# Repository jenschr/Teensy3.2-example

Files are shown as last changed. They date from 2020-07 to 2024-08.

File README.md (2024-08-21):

# Teensy3.2-example
A verified example PCB based on the Teensy 3.2 schematics. This repository holds the Kicad files to create your own Teensy 3.2 PCB. Design notes can be found on [my blog](https://flashgamer.com/blog/comments/teensy-3.2-kicad-example).

I'm a consultant based in Oslo/Norway, so [get in touch](https://maketronics.no/about/) if you need custom hardware based on Teensy 4.x (Since Teensy 3.x is no longer feasible due to parts shortage)

Pictures of the finished board can be [found here](images/).

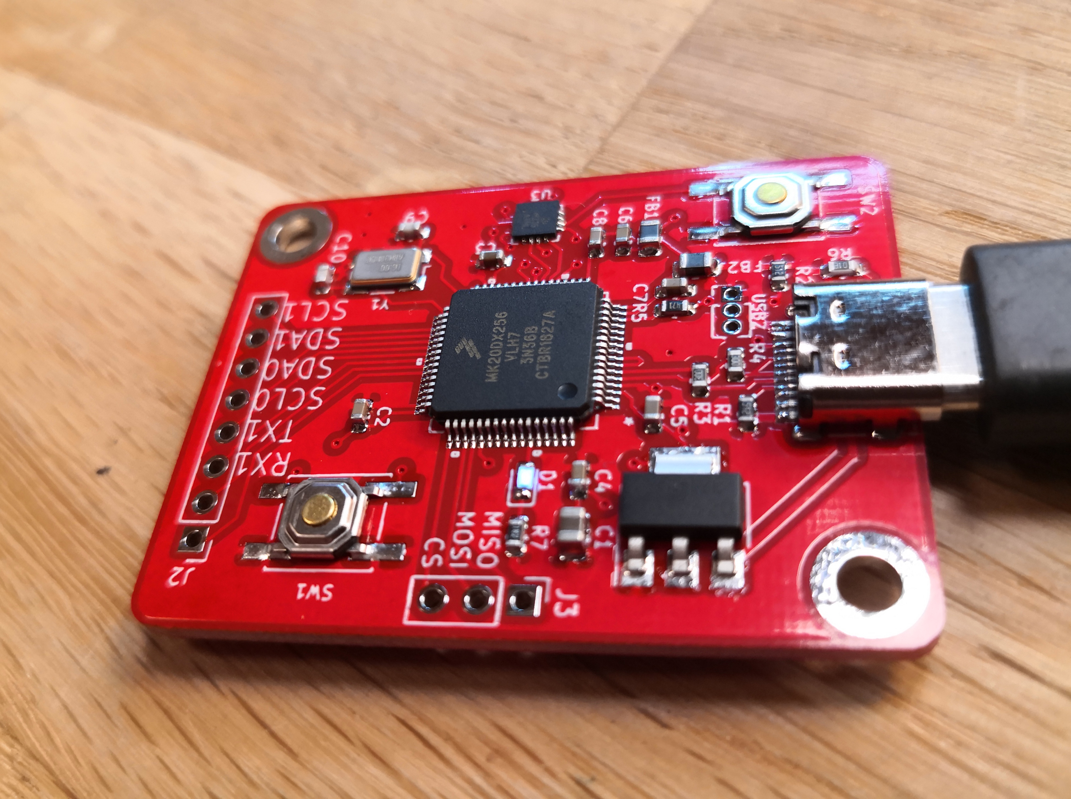
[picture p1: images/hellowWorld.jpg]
Finished PCB


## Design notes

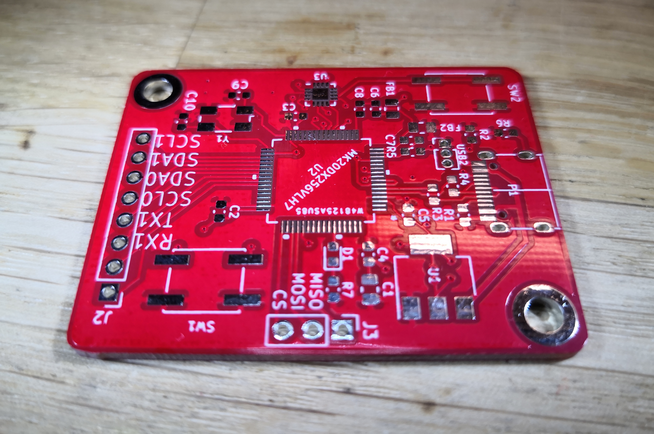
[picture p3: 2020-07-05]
images/unpopulated.jpg

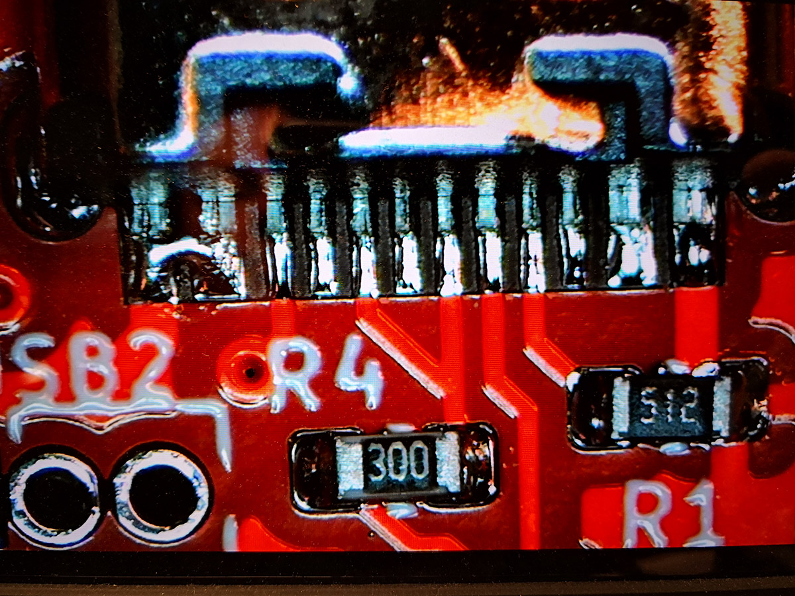
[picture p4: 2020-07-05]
images/short.jpg

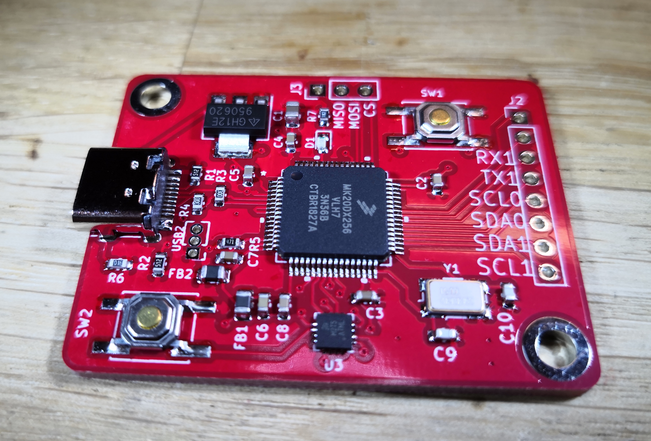
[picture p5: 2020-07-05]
images/populated_w_short_on_usb.jpg

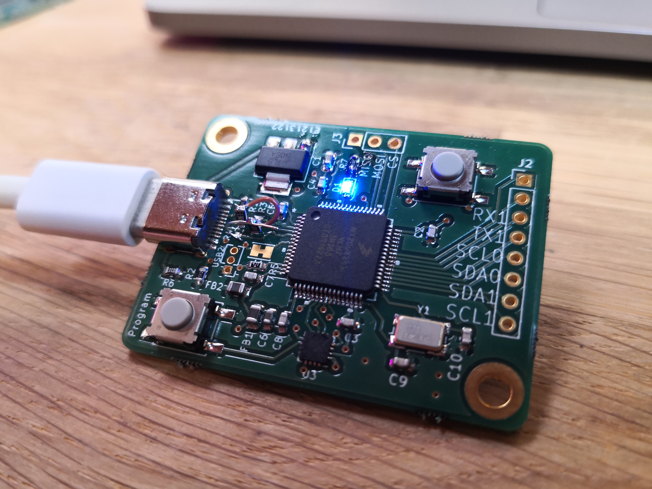
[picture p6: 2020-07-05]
images/version1.0_data_lines_swapped.jpg

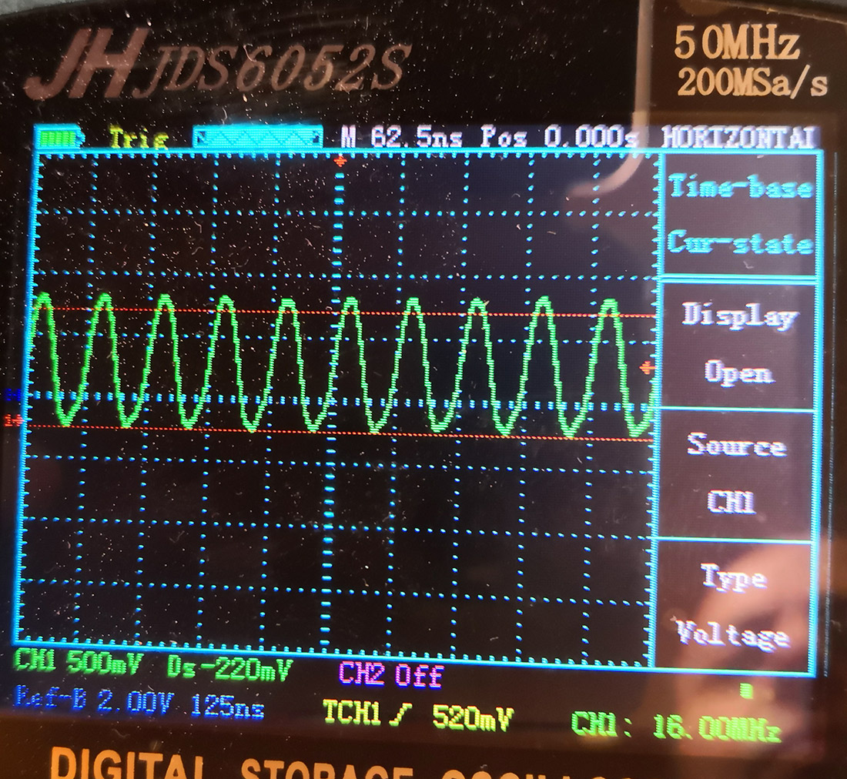
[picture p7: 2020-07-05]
images/oscillating.jpg

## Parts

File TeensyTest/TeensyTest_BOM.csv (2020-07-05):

Ref | Value | Footprint | MPN | MFGR
C1 | 10uF | Capacitor_SMD:C_0805_2012Metric
C2 | 0.1uF | Capacitor_SMD:C_0603_1608Metric
C3 | 0.1uF | Capacitor_SMD:C_0603_1608Metric
C4 | 0.1uF | Capacitor_SMD:C_0603_1608Metric
C5 | 0.1uF | Capacitor_SMD:C_0603_1608Metric
C6 | 2.2uF | Resistor_SMD:R_0603_1608Metric
C7 | 0.1uF | Capacitor_SMD:C_0603_1608Metric
C8 | 0.1uF | Capacitor_SMD:C_0603_1608Metric
C9 | 10pF | Capacitor_SMD:C_0603_1608Metric | 885012006002‎ | Wurth
C10 | 10pF | Capacitor_SMD:C_0603_1608Metric | 885012006002‎ | Wurth
D1 | LED_Small | LED_SMD:LED_0603_1608Metric
FB1 | Ferrite_Bead_Small | Resistor_SMD:R_0805_2012Metric | MZ1608-601Y | Bourns
FB2 | Ferrite_Bead_Small | Resistor_SMD:R_0805_2012Metric | MZ1608-601Y | Bourns
H1 | MountingHole | MountingHole:MountingHole_3.2mm_M3_DIN965_Pad
H2 | MountingHole | MountingHole:MountingHole_3.2mm_M3_DIN965_Pad
J2 | Conn_01x08_Female | Connector_PinHeader_2.54mm:PinHeader_1x08_P2.54mm_Vertical
J3 | Conn_01x03_Female | Connector_PinHeader_2.54mm:PinHeader_1x03_P2.54mm_Vertical
P1 | USB_C_Plug_USB2.0 | USB-C-Power-tester:TYPE-C-31-M-12 | TYPE-C-31-M-12 | Korean Hroparts Elec
R1 | 5.1k | Resistor_SMD:R_0603_1608Metric
R2 | 5.1k | Resistor_SMD:R_0603_1608Metric
R3 | 33R | Resistor_SMD:R_0603_1608Metric
R4 | 33R | Resistor_SMD:R_0603_1608Metric
R5 | 470R | Resistor_SMD:R_0603_1608Metric
R6 | 1M | Resistor_SMD:R_0603_1608Metric
R7 | 470R | Resistor_SMD:R_0603_1608Metric
SW1 | SW_Push | Button_Switch_SMD:SW_SPST_EVQQ2 | EVQ-Q2B03W | Panasonic
SW2 | SW_Push | Button_Switch_SMD:SW_SPST_EVQQ2 | EVQ-Q2B03W | Panasonic
U1 | AP2114H | Package_TO_SOT_SMD:SOT-223-3_TabPin2 | AP2114H-3.3TRG1
U2 | MK20DX256VLH7 | footprints:MK20DX256VLH7 | MK20DX256VLH7 | NXP
U3 | MKL02Z32VFG4 | Package_DFN_QFN:QFN-16-1EP_3x3mm_P0.5mm_EP1.8x1.8mm |  | PJRC
Y1 | Crystal_GND24 | Crystal:Crystal_SMD_Abracon_ABM3B-4Pin_5.0x3.2mm | ABM3B-16.000MHZ-10-1-U-T | Abracon
Source: | /Users/jensa/Dropbox/Hardware/Teensy3.2-example/TeensyTest/TeensyTest.sch
Date: | 2020 July 05, Sunday 18:20:21
Tool: | Eeschema (5.1.2-1)-1
Component Count: | 31

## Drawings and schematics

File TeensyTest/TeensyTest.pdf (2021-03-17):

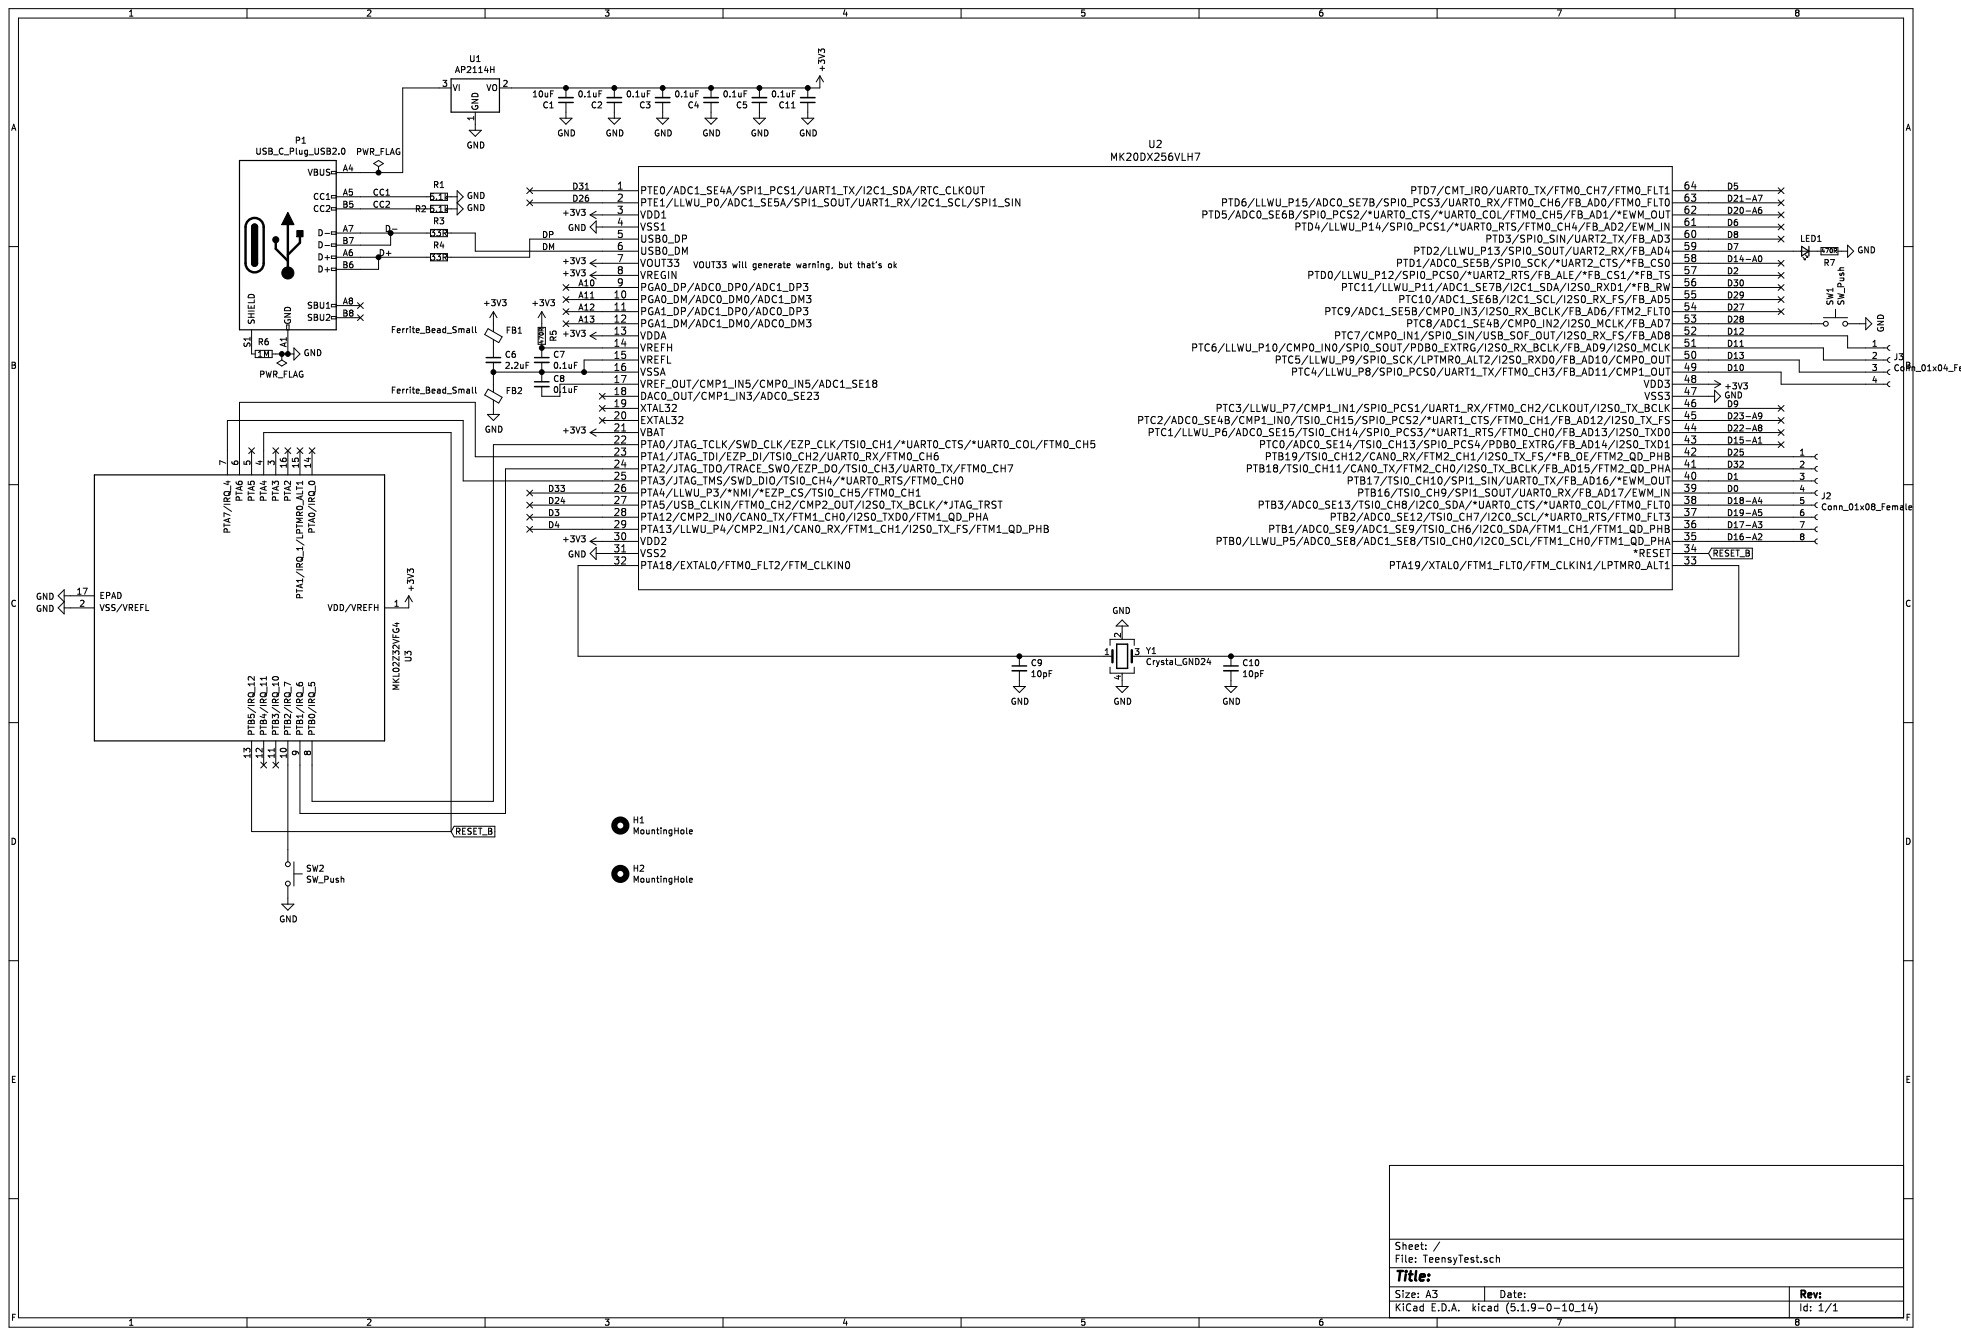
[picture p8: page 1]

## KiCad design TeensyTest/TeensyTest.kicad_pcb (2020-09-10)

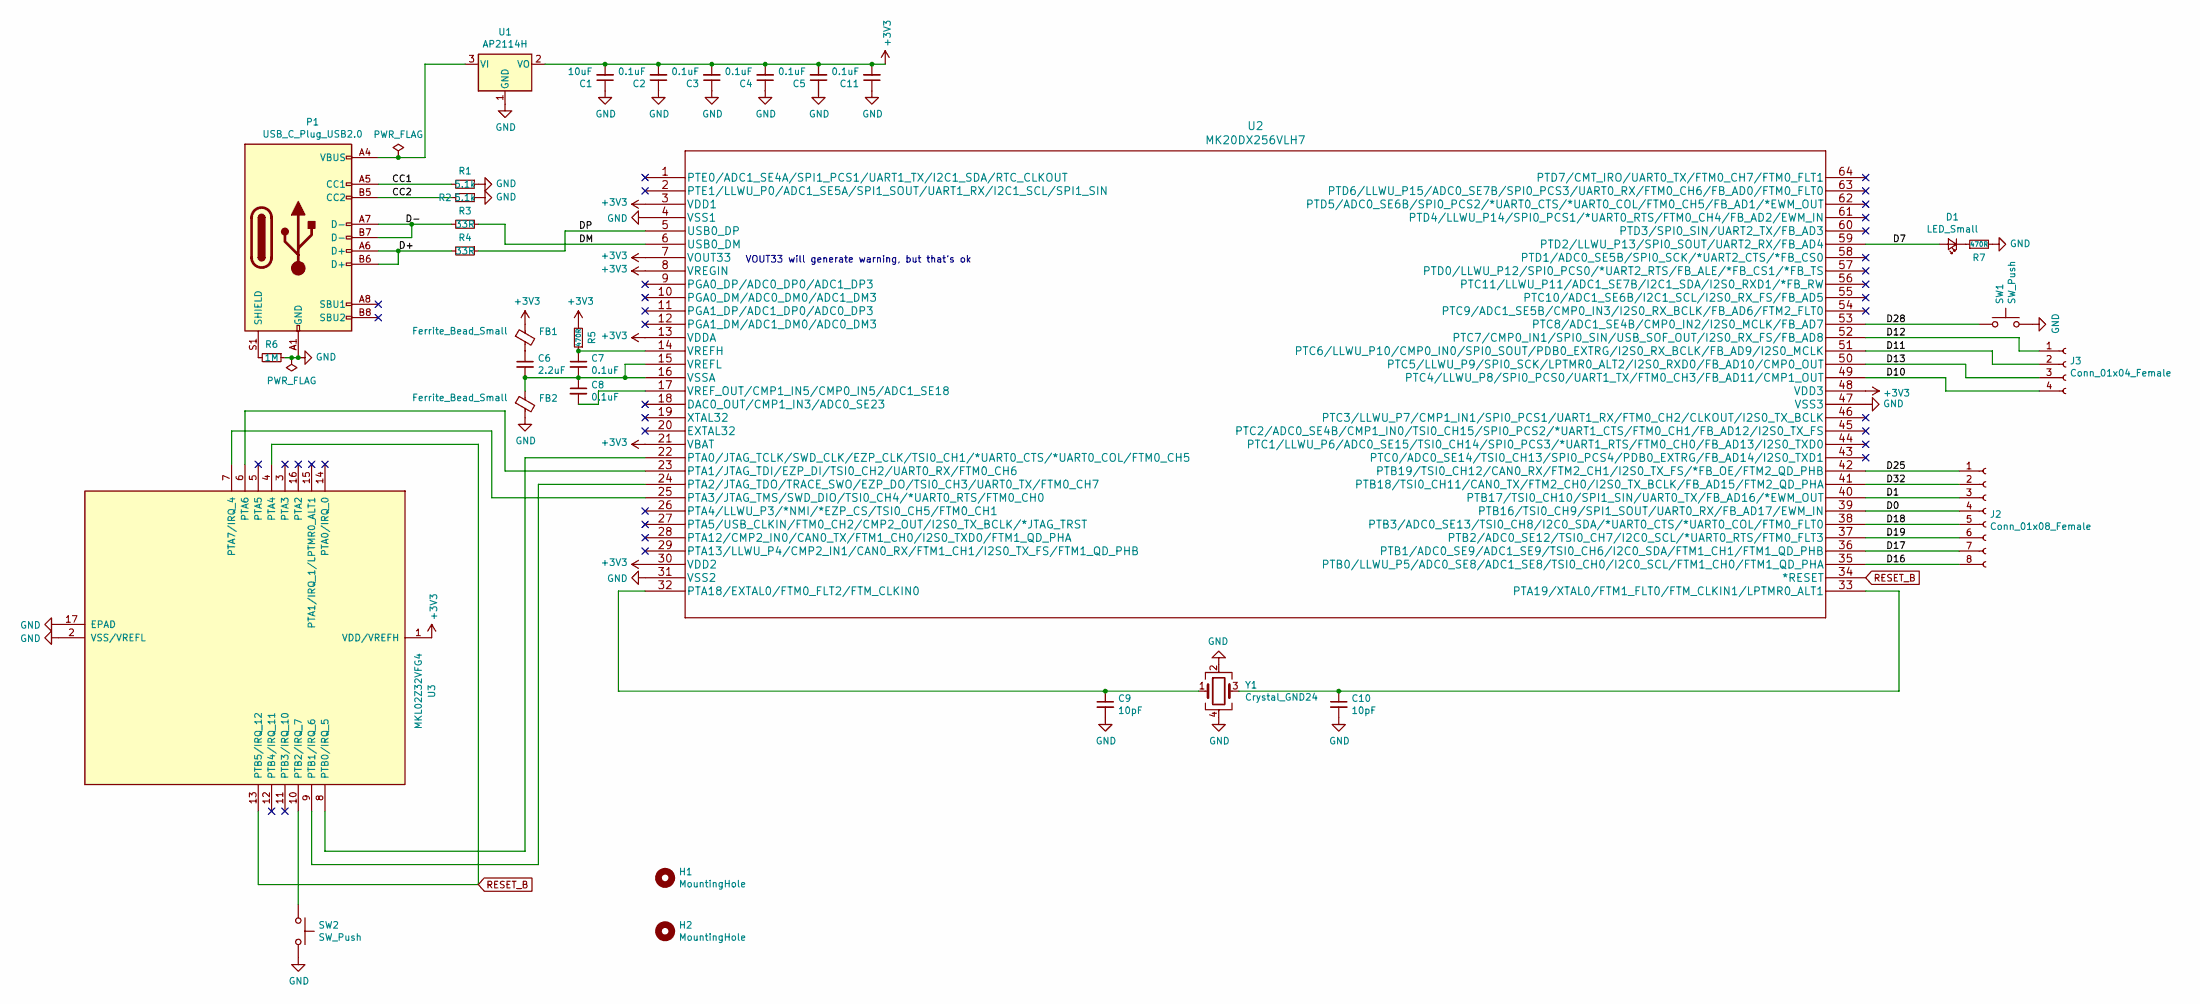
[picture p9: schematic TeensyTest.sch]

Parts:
C1: 10uF; C_0805_2012Metric
C2, C3, C4, C5, C7, C8, C11: 0.1uF; C_0603_1608Metric
C6: 2.2uF; R_0603_1608Metric
C9, C10: 10pF; C_0603_1608Metric; MPN 885012006002‎
D1: LED_Small; LED_0603_1608Metric
FB1, FB2: Ferrite_Bead_Small; R_0805_2012Metric; MPN MZ1608-601Y
H1, H2: MountingHole; MountingHole_3.2mm_M3_DIN965_Pad
J2: Conn_01x08_Female; PinHeader_1x08_P2.54mm_Vertical
J3: Conn_01x04_Female; PinHeader_1x04_P2.54mm_Vertical
P1: USB_C_Plug_USB2.0; TYPE-C-31-M-12; MPN TYPE-C-31-M-12
R1, R2: 5.1k; R_0603_1608Metric
R3, R4: 33R; R_0603_1608Metric
R5, R7: 470R; R_0603_1608Metric
R6: 1M; R_0603_1608Metric
SW1, SW2: SW_Push; SW_SPST_EVQQ2; MPN EVQ-Q2B03W
U1: AP2114H; SOT-223-3_TabPin2; MPN AP2114H-3.3TRG1
U2: MK20DX256VLH7; MPN MK20DX256VLH7
U3: MKL02Z32VFG4; QFN-16-1EP_3x3mm_P0.5mm_EP1.8x1.8mm
Y1: Crystal_GND24; Crystal_SMD_Abracon_ABM3B-4Pin_5.0x3.2mm; MPN ABM3B-16.000MHZ-10-1-U-T

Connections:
+3V3: C1.2, C2.2, C3.2, C4.2, C5.2, C11.2, FB1.1, R5.2, U1.2 (VO), U2.3 (VDD1), U2.7 (VOUT33), U2.8 (VREGIN), U2.13 (VDDA), U2.21 (VBAT), U2.30 (VDD2), U2.48 (VDD3), U3.1 (VDD/VREFH)
/CC1: P1.A5 (CC1), R1.2
/CC2: P1.B5 (CC2), R2.2
/D0: J2.4, U2.39 (PTB16/TSI0_CH9/SPI1_SOUT/UART0_RX/FB_AD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)
/D1: J2.3, U2.40 (PTB17/TSI0_CH10/SPI1_SIN/UART0_TX/FB_AD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)
/D7: D1.2 (A), U2.59 (PTD2/LLWU_P13/SPI0_SOUT/UART2_RX/FB_AD4)
/D10: J3.4, U2.49 (PTC4/LLWU_P8/SPI0_PCS0/UART1_TX/FTM0_CH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)
/D11: J3.2, U2.51 (PTC6/LLWU_P10/CMP0_IN0/SPI0_SOUT/PDB0_E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)
/D12: J3.1, U2.52 (PTC7/CMP0_IN1/SPI0_SIN/USB_SOF_OUT/I2S0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)
/D13: J3.3, U2.50 (PTC5/LLWU_P9/SPI0_SCK/LPTMR0_ALT2/I2S0_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)
/D16: J2.8, U2.35 (PTB0/LLWU_P5/ADC0_SE8/ADC1_SE8/TSI0_CH0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)
/D17: J2.7, U2.36 (PTB1/ADC0_SE9/ADC1_SE9/TSI0_CH6/I2C0_SD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)
/D18: J2.5, U2.38 (PTB3/ADC0_SE13/TSI0_CH8/I2C0_SDA/*UART0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)
/D19: J2.6, U2.37 (PTB2/ADC0_SE12/TSI0_CH7/I2C0_SCL/*UART0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)
/D25: J2.1, U2.42 (PTB19/TSI0_CH12/CAN0_RX/FTM2_CH1/I2S0_T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)
/D28: SW1.1, U2.53 (PTC8/ADC1_SE4B/CMP0_IN2/I2S0_MCLK/FB_AD7)
/D32: J2.2, U2.41 (PTB18/TSI0_CH11/CAN0_TX/FTM2_CH0/I2S0_T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)
/D+: P1.A6 (D+), P1.B6 (D+), R4.2
/D-: P1.A7 (D-), P1.B7 (D-), R3.2
/DM: R3.1, U2.6 (USB0_DM)
/DP: R4.1, U2.5 (USB0_DP)
GND: C1.1, C2.1, C3.1, C4.1, C5.1, C9.2, C10.2, C11.1, FB2.2, P1.A1 (GND), P1.A12 (GND), P1.B1 (GND), P1.B12 (GND), R1.1, R2.1, R6.1, R7.2, SW1.2, SW2.2, U1.1 (GND), U2.4 (VSS1), U2.31 (VSS2), U2.47 (VSS3), U3.2 (VSS/VREFL), U3.17 (EPAD), Y1.2, Y1.4
unnamed: C6.1, FB1.2
unnamed: C6.2, C7.2, C8.1, FB2.1, U2.15 (VREFL), U2.16 (VSSA)
unnamed: C7.1, R5.1, U2.14 (VREFH)
unnamed: C8.2, U2.17 (VREF_OUT/CMP1_IN5/CMP0_IN5/ADC1_SE18)
unnamed: C9.1, U2.32 (PTA18/EXTAL0/FTM0_FLT2/FTM_CLKIN0), Y1.1
unnamed: C10.1, U2.33 (PTA19/XTAL0/FTM1_FLT0/FTM_CLKIN1/LPTMR0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), Y1.3
unnamed: D1.1 (K), R7.1
unnamed: P1.S1 (SHIELD), R6.2
unnamed: SW2.1, U3.10 (PTB2/IRQ_7)
unnamed: U2.22 (PTA0/JTAG_TCLK/SWD_CLK/EZP_CLK/TSI0_CH1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), U3.8 (PTB0/IRQ_5)
unnamed: U2.23 (PTA1/JTAG_TDI/EZP_DI/TSI0_CH2/UART0_RX/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), U3.6 (PTA6)
unnamed: U2.24 (PTA2/JTAG_TDO/TRACE_SWO/EZP_DO/TSI0_CH3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), U3.9 (PTB1/IRQ_6)
unnamed: U2.25 (PTA3/JTAG_TMS/SWD_DIO/TSI0_CH4/*UART0_R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), U3.7 (PTA7/IRQ_4)
RESET_B: U2.34 (*RESET), U3.4 (PTA4), U3.13 (PTB5/IRQ_12)
VBUS: P1.A4 (VBUS), P1.A9 (VBUS), P1.B4 (VBUS), P1.B9 (VBUS), U1.3 (VI)

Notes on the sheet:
VOUT33 will generate warning, but that’s ok

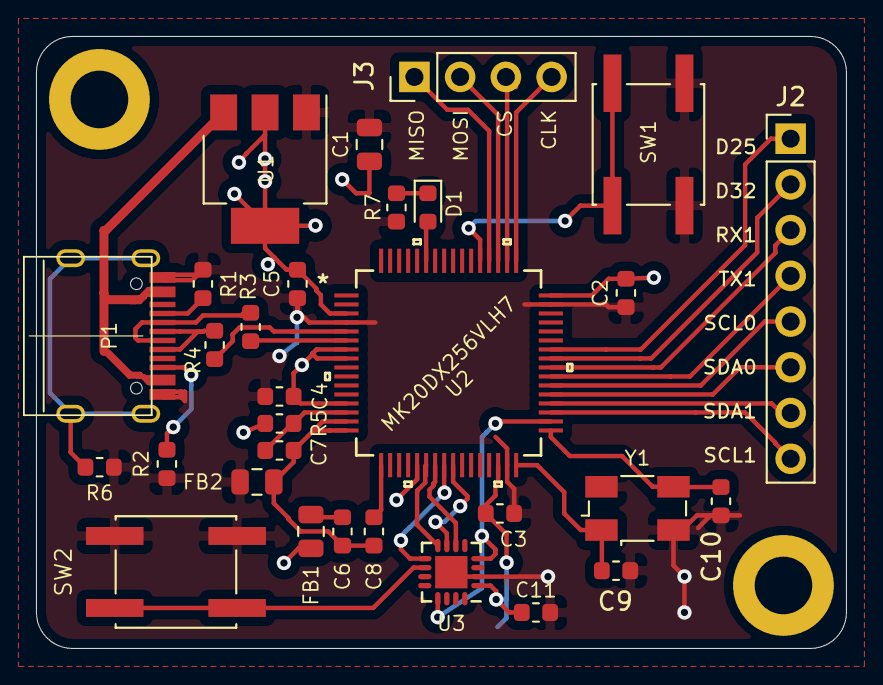
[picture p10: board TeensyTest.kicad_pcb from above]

Board: 2 copper layers, 45.0 x 34.0 mm, 32 parts (0 on the bottom side), 37 nets.

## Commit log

2020-07-05 First commit after verifying v2 of the board
    [TeensyTest-B_Cu.gbr, TeensyTest-B_Mask.gbr, TeensyTest-B_Paste.gbr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]
2020-07-05 Added BOM, added more pictures, added MPN's for some parts
    [TeensyTest.sch, TeensyTest_BOM.csv]
2020-07-05 Added picture of the first board that had data lines swapped. Fixed with bodge wires...
2020-07-17 Moved C4 closer to pins 7 & 8
    [TeensyTest.kicad_pcb]
2020-07-17 Added extra 100nF cap for MKL02
    [TeensyTest.kicad_pcb, TeensyTest.sch]
2020-09-10 added Teensy3.2 schematic as reference, added CLK pin for SPI comms
    [TeensyTest.kicad_pcb, TeensyTest.sch]
2021-03-17 Added naming to all files, pdf schematic

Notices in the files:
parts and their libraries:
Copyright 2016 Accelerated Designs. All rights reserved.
